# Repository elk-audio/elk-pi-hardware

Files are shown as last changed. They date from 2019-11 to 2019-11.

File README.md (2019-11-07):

# Elk Pi hardware documents

Full hardware project for the Elk Pi expansion Hat for the Raspberry Pi.

Directory contents:

  * [/Altium_files](Altium_files): Altium Project (ElkPi.PrjPcb), schematic documents (*.SchDoc), PCB document (ElkPi.PcbDoc), library files (Sika_revb.SchLib, Sika_revb.PcbLib)  
	  
  * [/Production_files/PCB_manufacturing](/Production_files/PCB_manufacturing): Gerber and drill files ready for PCB manufacturing  
	  
  * [/Production_files/PCB_Assembly](/Production_files/PCB_Assembly): Pick & Place file and assembly drawings (Top and Bottom)  
	  
  * [ElkPi_BOM.pdf](ElkPi_BOM.pdf): Bill Of Materials  
	  
  * [ElkPi_schematics.pdf](ElkPi_schematics.pdf): schematics capture file  
	  
---
Copyright 2019 *Modern Ancient Instruments Networked AB*, dba *Elk*

<br />This work is licensed under a <a rel="license" href="http://creativecommons.org/licenses/by-sa/4.0/">Creative Commons Attribution-ShareAlike 4.0 International License</a>.

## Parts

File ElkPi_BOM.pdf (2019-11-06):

| Elk Pi hat BOM | cc-by-sa Copyright Modern Ancient Instruments Networked AB, dba Elk 2019-11-06
# | Designator | Description | (per board) Qty | DNP | C | R | L | Footprint | rating | Dielectric | Manufacturer | Part Number | Manufacture r Lifecycle | Supplier | Supplier Part Number | Comment

## Passive Components

1 | C1_I1, C1_I2, C1_I3, C1_I4, C1_I5, C1_I6 | Cap Ceramic 10% | 6 | | 750pF | 0603 | 50V | C0G | Samsung | CL10C751JB8NNNC | Volume Production | Digi-Key | 1276-2336-6-ND (https://www.digikey.se/products/en?keywords=1276-2336-6-ND)
2 | C2_I1, C2_I2, C2_I3, C2_I4, C2_I5, C2_I6, C5_I1, C5_I2, C5_I3, C5_I4, C5_I5, C5_I6, C8, C9, C11, C13_O1, C13_O2, C13_O3, C25, C26, C27, C28, C29, C30, C32, C33, C35, C37, C42, C43, C45, C46, C47, C48, C49, C50, C51, C52, C53, C60, C63, C69, C73, C88, C89, C96, C97, C98, C99,C106 | Cap Ceramic 10% | 50 | | 100nF | 0603 | 16V | X7R | Samsung | CL10B104KO8NNNC | Volume Production | Digi-Key | 1276-1005-1-ND (https://www.digikey.se/products/en?keywords=1276-1005-1-ND)
3 | C62, C65 | Cap Ceramic 5% | 2 | | 220pF | 0603 | 50V | C0G | Samsung | CL10C221JB8NNNC | Volume Production | Digi-Key | 1276-1048-1-ND (https://www.digikey.se/products/en?keywords=1276-1048-1-ND)
4 C3_I1, C3_I2, C3_I3, C3_I4, C3_I5, C3_I6, C14_O1, C14_O2, C14_O3, C17_O1, C17_O2, | C17_O3, C19_O1, C19_O2, C19_O3, C22_O1, C22_O2, C22_O3, C102, C105 | Cap Aluminum Electrolytic 20% | 20 | | 22uF | Radial, Can - SMD | 35V | | Nichicon | UUQ1V220MCL1GB | Volume Production | Digi-Key | 493-17495-6-ND (https://www.digikey.se/products/en?keywords=493-17495-6-ND) | Height= 5.40mm Substitute: UWT1V220MCL1GB
5 | C4_I1, C4_I2, C4_I3, C4_I4, C4_I5, C4_I6 | Cap Ceramic 5% | 6 | | 22pF | 0603 | 50V | C0G | Samsung | CL10C220JB8NNNC | Volume Production | Digi-Key | 1276-1023-6-ND (https://www.digikey.se/products/en?keywords=1276-1023-6-ND)
6 | C6, C7, C58, C82 | Cap Ceramic 10% | 4 | | 1uF | 0805 | 16V | X7R | Samsung | CL21B105KAFNNNE | End of Life | Digi-Key | 1276-1066-6-ND (https://www.digikey.se/products/en?keywords=1276-1066-6-ND)
7 | C10 | Cap Ceramic 10% | 1 | | 1.5nF | 0603 | 16V | C0G | Samsung | CL10C152JB8NNNC | Volume Production | Digi-Key | 1276-2203-6-ND (https://www.digikey.se/products/en?keywords=1276-2203-6-ND)
8 C12_O1, C12_O2, C12_O3, C15_O1, C15_O2, C15_O3, C16_O1, C16_O2, C16_O3, C18_O1, | C18_O2, C18_O3, C20_O1, C20_O2, C20_O3, C21_O1, C21_O2, C21_O3 | Cap Ceramic 10% | 18 | | 1nF | 0603 | 16V | C0G | Samsung | CL10C102JB8NNNC | Volume Production | Digi-Key | 1276-1091-1-ND (https://www.digikey.se/products/en?keywords=1276-1091-1-ND)
9 | C23, C24 | Cap Ceramic 10% | 2 | | 16pF | 0603 | 50V | C0G | Samsung | CL10C160JB8NNNC | Volume Production | Digi-Key | 1276-2204-1-ND (https://www.digikey.se/products/en?keywords=1276-2204-1-ND)
10 | C31, C34, C36, C38, C39, C40, C41 | Capacitor Ceramic 20% | 7 | | 10uF | 0805 | 10V | X5R | Samsung | CL21A106MPFNNNE | Volume Production | Digi-Key | 1276-1144-6-ND (https://www.digikey.se/products/en?keywords=1276-1144-6-ND)
11 | C44, C67 | Cap Ceramic 10% | 2 | | 1uF | 0603 | 16V | X7R | Samsung | CL10B105KO8NFNC | Volume Production | Digi-Key | 1276-1943-6-ND (https://www.digikey.se/products/en?keywords=1276-1943-6-ND)
12 | C54, C56, C100, C103 | Cap Film 10% | 4 | | 1µF | 2824 | 50V | PEN | KEMET | LDECE4100KA5N00 | Volume Production | Digi-Key | 399-6416-1-ND (https://www.digikey.se/products/en?keywords=399-6416-1-ND)
13 | C55, C57 | Cap Aluminum Electrolytic 20% | 2 | | 100uF | Radial, Can - SMD | 25V | | Nichicon | UWT1E101MCL1GS | Volume Production | Digi-Key | 493-2190-1-ND (https://www.digikey.se/products/en?keywords=493-2190-1-ND) | Height = 7.70mm
14 | C59, C85 | Cap Ceramic 10% | 2 | | 10uF | 1210 | 25V | X7R | Samsung | CL32B106KAJNNNE | Volume Production | Digi-Key | 1276-1807-6-ND (https://www.digikey.se/products/en?keywords=1276-1807-6-ND)
15 | C61 | Capacitor Tantalum 10% | 1 | | 100uF | 2312 | 10V | | KEMET | T491C107K010AT | Volume Production | Digi-Key | 399-8338-1-ND (https://www.digikey.se/products/en?keywords=399-8338-1-ND)
16 | C64, C66 | Cap Ceramic 10% | 2 | | 330nF | 0603 | 16V | X7R | Samsung | CL10B334KO8NNNC | Volume Production | Digi-Key | 1276-2048-1-ND (https://www.digikey.se/products/en?keywords=1276-2048-1-ND)
17 | C68, C70, C71, C72, C74, C75, C76, C77, C78, C79, C80, C81 | Cap Ceramic 5% | 12 | | 47pF | 0603 | 50V | C0G | Samsung | CL10C470JB8NNNC | Volume Production | Digi-Key | 1276-1037-6-ND (https://www.digikey.se/products/en?keywords=1276-1037-6-ND)
18 | C83 | Cap Aluminium Electrolytic 20% | 1 | | 47µF | Radial, Can - SMD | 10V | | Panasonic | EEE1AA470WR | Volume Production | Digi-Key | PCE3875CT-ND (https://www.digikey.se/products/en?keywords=PCE3875CT-ND) | Height: 5.40mm
19 | C84, C86 | Cap Ceramic 10% | 2 | | 4.7uF | 0805 | 16V | X7R | Samsung | CL21B475KOFNFNE | Volume Production | Digi-Key | 1276-2970-6-ND (https://www.digikey.se/products/en?keywords=1276-2970-6-ND)
20 | C87 | Cap Ceramic 10% | 1 | | 22uF | 1210 | 25V | X7R | Samsung | CL32B226KAJNNNE | Volume Production | Digi-Key | 1276-3392-6-ND (https://www.digikey.se/products/en?keywords=1276-3392-6-ND)
21 | C90 | Cap Ceramic 10% | 1 | | 2.2uF | 0603 | 10V | X7R | Samsung | CL10B225KP8NNNC | Volume Production | Digi-Key | 1276-1134-6-ND (https://www.digikey.se/products/en?keywords=1276-1134-6-ND)
22 | C91 | Generic Capacitor slot | 1 | DNP | | 0603
23 | C92, C101, C104 | Cap Ceramic ±0.25pF | 3 | | 10pF | 0603 | 50V | C0G | Samsung | CL10C100CB8NNNC | Volume Production | Digi-Key | 1276-1069-1-ND (https://www.digikey.se/products/en?keywords=1276-1069-1-ND)
24 | C93 | Cap Multilayer Ceramic 20% | 1 | | 2.2uF | 0805 | 10V | X5R | Taiyo Yuden | LMK212BJ225MG-T | Volume Production | Digi-Key | 587-5919-1-ND (https://www.digikey.se/products/en?keywords=587-5919-1-ND)
25 | C94 | Cap Ceramic 20% | 1 | | 4.7uF | 1206 | 16V | X5R | KEMET | C1206C105M3RACT U | Volume Production | Digi-Key | 399-8148-6-ND (https://www.digikey.se/products/en?keywords=399-8148-6-ND)

| Elk Pi hat BOM | cc-by-sa Copyright Modern Ancient Instruments Networked AB, dba Elk 2019-11-06
# | Designator | Description | (per board) Qty | DNP | C | R | L | Footprint | rating | Dielectric | Manufacturer | Part Number | Manufacture r Lifecycle | Supplier | Supplier Part Number | Comment

26 | C95 | Cap Ceramic 20% | 1 | | 47uF | | | 1210 | 6.3V | X5R | Samsung | CL32A476MQJNNNE | Volume Production | Digi-Key | 1276-3381-6-ND (https://www.digikey.se/products/en?keywords=1276-3381-6-ND)
27 | D1 | Standard LED, Dome Lens, Red | 1 | | | | | 0603 | | | Kingbright | APTD1608LSURCK | Volume Production | Digi-Key | 754-2038-1-ND (https://www.digikey.se/products/en?keywords=754-2038-1-ND)
28 | D2, D5 | Standard LED, Dome Lens, Green | 2 | | | | | 0603 | | | Kingbright | APTD1608LCGCK | Volume Production | Digi-Key | 754-2037-1-ND (https://www.digikey.se/products/en?keywords=754-2037-1-ND)
29 | D3 | Diodes - General Purpose, Power, Switching 100volt 350mA 4ns | 1 | | | | | SOD-323F | | | ON Semiconductor | 1N914BWS | Volume Production | Digi-Key | 1N914BWSCT-ND (https://www.digikey.se/products/en?keywords=1N914BWSCT-ND)
30 | D4 | Diode Schottky 20V 500mA | 1 | | | | | SOD-123 | | | ON Semiconductor | MBR0520LT1G | Volume Production | Digi-Key | MBR0520LT1GOSCT- (https://www.digikey.se/products/en?keywords=MBR0520LT1GOSCT-ND) ND (https://www.digikey.se/products/en?keywords=MBR0520LT1GOSCT-ND)
31 | D6 | TVS DIODE 5VWM 9.2VC DO214AA | 1 | | | | | DO-214AA | | | Littelfuse Inc. | SMBJ5.0A | Volume Production | Digi-Key | SMBJ5.0ALFCT-ND (https://www.digikey.se/product-detail/en/littelfuse-inc/SMBJ5.0A/SMBJ5.0ALFCT-ND/285951)
32 | F1 | PTC Resettable Fuse 2.5A(hold) 5A(trip) | 1 | | | 100mR | | 1812 | 16V | | Bourns | MF-MSMF250/16X-2 | Volume Production | Digi-Key | MF-MSMF250/16X-2CT- ND (https://www.digikey.se/products/en?keywords=MF-MSMF250%2F16X-2CT-ND)
33 | FB1, FB2, FB3, FB4, FB6 | Signal Line Ferrite Bead, 0.5OHM1 kOhms @ 100MHz | 5 | | | | | 0603 | | | TDK | MMZ1608R102ATA00 | Volume Production | Digi-Key | 445-1548-1-ND (https://www.digikey.se/products/en?keywords=445-1548-1-ND)
34 | FB5 | Ferrite Bead, 470 Ohms @ 100MHz | 1 | | | | | 0603 | | | Murata | BLM18EG471SN1D | Volume Production | Digi-Key | 490-3993-1-ND (https://www.digikey.se/products/en?keywords=490-3993-1-ND)
35 | L1 | Shielded Wirewound Inductor 2.7A | 1 | | | | 2.2uH | Non Standard | | | Taiyo Yuden | NR6020T2R2N | Volume Production | Digi-Key | 587-2071-1-ND (https://www.digikey.se/products/en?keywords=587-2071-1-ND)
36 | L2 | INDUCTOR POWER 10UH 1.04A SMD | 1 | | | | 10uh | CR43-100MC | | | Sumida | CR43NP-100MC | Volume Production | Digi-Key | 308-2329-1-ND (https://www.digikey.se/products/en?keywords=308-2329-1-ND)
37 R1_I1, R1_I2, R1_I3, R1_I4, R1_I5, R1_I6, R5_I1, R5_I2, R5_I3, R5_I4, R5_I5, R5_I6, R6_I1, | R6_I2, R6_I3, R6_I4, R6_I5, R6_I6, R68, R69 | Resistor, Ceramic 1% | 20 | | | 1.5k | | 0603 | | | Bourns | CR0603-FX-1501ELF | Volume Production | Digi-Key | CR0603-FX-1501ELFCT- ND (https://www.digikey.se/products/en?keywords=CR0603-FX-1501ELFCT-ND)
38 | R2_I1, R2_I2, R2_I3, R2_I4, R2_I5, R2_I6 | Resistor, Ceramic 1% | 6 | | | 3k | | 0603 | | | Bourns | CR0603-FX-3001ELF | Volume Production | Digi-Key | CR0603-FX-3001ELFCT- (https://www.digikey.se/products/en?keywords=CR0603-FX-3001ELFCT-ND) ND (https://www.digikey.se/products/en?keywords=CR0603-FX-3001ELFCT-ND)
39 R3_I1, R3_I2, R3_I3, R3_I4, R3_I5, R3_I6, R7_I1, R7_I2, R7_I3, R7_I4, R7_I5, R7_I6, R13_O1, | R13_O2, R13_O3, R21_O1, R21_O2, R21_O3 | Resistor, Ceramic 1% | 18 | | | 47R | | 1206 | | | Bourns | CR1206-FX-47R0ELF | Volume Production | Digi-Key | CR1206-FX- 47R0ELFCT-ND (https://www.digikey.se/products/en?keywords=CR1206-FX-47R0ELFCT-ND)
40 | R4_I1, R4_I2, R4_I3, R4_I4, R4_I5, R4_I6, R38, R42, R59, R62, R64, R67, R80, R87, R94, R102, R125, R132 | Resistor, Ceramic 1% | 18 | | | 100k | | 0603 | | | Bourns | CR0603-FX-1003ELF | Volume Production | Digi-Key | CR0603-FX-1003ELFCT- (https://www.digikey.se/products/en?keywords=CR0603-FX-1003ELFCT-ND) ND (https://www.digikey.se/products/en?keywords=CR0603-FX-1003ELFCT-ND)
41 | R8, R53, R135 | Resistor, Ceramic 1% | 3 | | | 560R | | 0603 | | | Bourns | CR0603-FX-5600ELF | Volume Production | Digi-Key | CR0603-FX-5600ELFCT- (https://www.digikey.se/products/en?keywords=CR0603-FX-5600ELFCT-ND) ND (https://www.digikey.se/products/en?keywords=CR0603-FX-5600ELFCT-ND)
42 | R9 | Resistor, Ceramic 1% | 1 | | | 604k | | 0603 | | | Bourns | CR0603-FX-6043ELF | Volume Production | Mouser | 652-CR0603-FX6043ELF (https://eu.mouser.com/ProductDetail/Bourns/CR0603-FX-6043ELF)
43 R10_O1, R10_O2, R10_O3, R17_O1, R17_O2, R17_O3, R18_O1, R18_O2, R18_O3, R25_O1, | R25_O2, R25_O3 | Resistor, Ceramic 1% | 12 | 3.6k | 0603 | Bourns | CR0603-FX-3601ELF | Volume Production | Digi-Key | CR0603-FX-3601ELFCT- ND (https://www.digikey.se/products/en?keywords=CR0603-FX-3601ELFCT-ND)
44 R11_O1, R11_O2, R11_O3, R14_O1, R14_O2, R14_O3, R19_O1, R19_O2, R19_O3, R22_O1, | R22_O2, R22_O3 | Resistor, Ceramic 1% | 12 | 6.8k | 0603 | Bourns | CR0603-FX-6801ELF | Volume Production | Digi-Key | CR0603-FX-6801ELFCT- ND (https://www.digikey.se/products/en?keywords=CR0603-FX-6801ELFCT-ND)
45 R12_O1, R12_O2, R12_O3, R15_O1, R15_O2, R15_O3, R20_O1, R20_O2, R20_O3, R23_O1, | R23_O2, R23_O3 | Resistor, Ceramic 1% | 12 | 360R | 0603 | Bourns | CR0603-FX-3600ELF | End of Life | Digi-Key | CR0603-FX-3600ELFCT- ND (https://www.digikey.se/products/en?keywords=CR0603-FX-3600ELFCT-ND)
46 | R16_O1, R16_O2, R16_O3, R24_O1, R24_O2, R24_O3, R58, R61, R63, R66, R127, R134 | Resistor, Ceramic 1% | 12 | 47k | 0603 | Bourns | CR0603-FX-4702ELF | Volume Production | Digi-Key | CR0603-FX-4702ELFCT- (https://www.digikey.se/products/en?keywords=CR0603-FX-4702ELFCT-ND) ND (https://www.digikey.se/products/en?keywords=CR0603-FX-4702ELFCT-ND)
47 | R26, R32,R33, R34, R106, R126, R133 | Resistor, Ceramic 1% | 7 | 0R | 0603 | Bourns | CR0603-J/-000ELF | Volume Production | Digi-Key | CR0603-J/-000ELFCT- (https://www.digikey.se/products/en?keywords=CR0603-J%2F-000ELFCT-ND) ND (https://www.digikey.se/products/en?keywords=CR0603-J%2F-000ELFCT-ND)
48 | R27, R28, R29, R43, R44, R45, R46, R47, R48, R49, R55, R56, R76, R114, R115, R116, R117, R118, R119, R120 | Resistor, Ceramic 1% | 20 | 22R | 0603 | Samsung | RC1608F220CS | Volume Production | Digi-Key | 1276-4511-6-ND (https://www.digikey.se/products/en?keywords=1276-4511-6-ND)
49 | R35, R37, R39, R41, R112 | Resistor, Ceramic 1% | 5 | 1k | 0603 | Bourns | CR0603-FX-1001ELF | Volume Production | Digi-Key | CR0603-FX-1001ELFCT- (https://www.digikey.se/products/en?keywords=CR0603-FX-1001ELFCT-ND) ND (https://www.digikey.se/products/en?keywords=CR0603-FX-1001ELFCT-ND)
50 | R50 | Potentiometers Dual Unit 10mm, 15A insertion (2mm) | 1 | 10k | Non Standard | Alps Electric | RK10J12E0A0A | Volume Production | Mouser | 688-RK10J12E0A0A (https://eu.mouser.com/ProductDetail/ALPS/RK10J12E0A0A)
51 | R52, R54 | Resistor, Ceramic 1% | 2 | 20k | 0603 | Bourns | CR0603-FX-2002ELF | Volume Production | Digi-Key | CR0603-FX-2002ELFCT- (https://www.digikey.se/products/en?keywords=CR0603-FX-2002ELFCT-ND) ND (https://www.digikey.se/products/en?keywords=CR0603-FX-2002ELFCT-ND)
52 | R60, R65, R82, R88, R96, R103, R122, R129 | Resistor, Ceramic 1% | 8 | 47R | 0603 | Bourns | CR0603-FX-47R0ELF | Volume Production | Digi-Key | CR0603-FX- (https://www.digikey.se/products/en?keywords=CR0603-FX-47R0ELFCT-ND) 47R0ELFCT-ND (https://www.digikey.se/products/en?keywords=CR0603-FX-47R0ELFCT-ND)

| Elk Pi hat BOM | cc-by-sa Copyright Modern Ancient Instruments Networked AB, dba Elk 2019-11-06
# | Designator | Description | (per board) Qty | DNP | C | R | L | Footprint | rating | Dielectric | Manufacturer | Part Number | Manufacture r Lifecycle | Supplier | Supplier Part Number | Comment

53 | R70 | Resistor, Ceramic 1% | 1 | | | 470 | | 0603 | | | Bourns | CR0603-FX-4700ELF | Volume Production | Digi-Key | CR0603-FX-4700ELFCT- (https://www.digikey.se/products/en?keywords=CR0603-FX-4700ELFCT-ND) ND (https://www.digikey.se/products/en?keywords=CR0603-FX-4700ELFCT-ND)
54 | R71 | Resistor, Ceramic 1% | 1 | | | 220R | | 0603 | | | Bourns | CR0603-FX-2200ELF | Volume Production | Digi-Key | CR0603-FX-2200ELFCT- (https://www.digikey.se/products/en?keywords=CR0603-FX-2200ELFCT-ND) ND (https://www.digikey.se/products/en?keywords=CR0603-FX-2200ELFCT-ND)
55 | R72, R75 | Resistor, Ceramic 1% | 2 | | | 51R | | 0603 | | | Bourns | CR0603-FX-51R0ELF | Volume Production | Digi-Key | CR0603-FX- (https://www.digikey.se/products/en?keywords=CR0603-FX-51R0ELFCT-ND) 51R0ELFCT-ND (https://www.digikey.se/products/en?keywords=CR0603-FX-51R0ELFCT-ND)
56 | R31, R73, R74, R110 | Resistor, Ceramic 1% | 4 | DNP | | 0R | | 0603 | | | Bourns | CR0603-J/-000ELF | Volume Production | Digi-Key | CR0603-J/-000ELFCT- (https://www.digikey.se/products/en?keywords=CR0603-J%2F-000ELFCT-ND) ND (https://www.digikey.se/products/en?keywords=CR0603-J%2F-000ELFCT-ND)
57 | R77, R30, R36, R40, R51, R57, R113, R136, R137 | Resistor, Ceramic 1% | 9 | | | 10k | | 0603 | | | Bourns | CR0603-FX-1002ELF | Volume Production | Digi-Key | CR0603-FX-1002ELFCT- (https://www.digikey.se/products/en?keywords=CR0603-FX-1002ELFCT-ND) ND (https://www.digikey.se/products/en?keywords=CR0603-FX-1002ELFCT-ND)
58 | R78, R85, R92, R99 | Resistor, Ceramic 1% | 4 | | | 150k | | 0603 | | | Bourns | CR0603-FX-1503ELF | Volume Production | Digi-Key | CR0603-FX-1503ELFCT- (https://www.digikey.se/products/en?keywords=CR0603-FX-1503ELFCT-ND) ND (https://www.digikey.se/products/en?keywords=CR0603-FX-1503ELFCT-ND)
59 | R79, R81, R83, R84, R86, R89, R90, R91, R93, R95, R97, R98, R100, R101, R104, R105 | Resistor, Ceramic 1% | 16 | | | 49.9k | | 0603 | | | Bourns | CR0603-FX-4992ELF | Volume Production | Digi-Key | CR0603-FX-4992ELFCT- (https://www.digikey.se/products/en?keywords=CR0603-FX-4992ELFCT-ND) ND (https://www.digikey.se/products/en?keywords=CR0603-FX-4992ELFCT-ND)
60 | R107 | Resistor, Ceramic 1% | 1 | | | 15k | | 0603 | | | Bourns | CR0603-FX-1502ELF | Volume Production | Digi-Key | CR0603-FX-1502ELFCT- (https://www.digikey.se/products/en?keywords=CR0603-FX-1502ELFCT-ND) ND (https://www.digikey.se/products/en?keywords=CR0603-FX-1502ELFCT-ND)
61 | R108 | Resistor, Ceramic 0.1% | 1 | | | 2.32k | | 0603 | | | Panasonic | ERA-3AEB2321V | Volume Production | Digi-Key | P2.32KDBCT-ND (https://www.digikey.se/products/en?keywords=P2.32KDBCT-ND)
62 | R109 | Resistor, Ceramic 1% | 1 | | | 4.7k | | 0603 | | | Bourns | CR0603-FX-4701ELF | Volume Production | Digi-Key | CR0603-FX-4701ELFCT- (https://www.digikey.se/products/en?keywords=CR0603-FX-4701ELFCT-ND) ND (https://www.digikey.se/products/en?keywords=CR0603-FX-4701ELFCT-ND)
63 | R111 | Resistor, Ceramic 1% | 1 | | | 102k | | 0603 | | | Bourns | CR0603-FX-1023ELF | End of Life | Digi-Key | CR0603-FX-1023ELFCT- (https://www.digikey.se/products/en?keywords=CR0603-FX-1023ELFCT-ND) ND (https://www.digikey.se/products/en?keywords=CR0603-FX-1023ELFCT-ND)
64 | R123, R124,R130, R131 | Resistor, Ceramic 1% | 4 | | | 2M | | 0603 | | | Panasonic | ERJ-3EKF2004V | Volume Production | Digi-Key | P2.00MHCT-ND (https://www.digikey.se/product-detail/en/panasonic-electronic-components/ERJ-3EKF2004V/P2.00MHCT-ND/282732)
65 | X1 | Crystal 27.0000MHZ 10pF | 1 | | | | | 4-SMD, No Lead | | | TXC | 7M-27.000MEEQ-T | Volume Production | Digi-Key | 887-1328-2-ND (https://www.digikey.se/products/en?keywords=887-1328-2-ND) | Size: 3.2mm x 2.5mm

## Active Components

66 | T1, T2 | Transistor NPN 40V 0.2A | 2 | SOT-23-3 | ON Semiconductor | MMBT3904LT1G | Volume Production | Digi-Key | MMBT3904LT1GOSCT- (https://www.digikey.se/product-detail/en/on-semiconductor/MMBT3904LT1G/MMBT3904LT1GOSCT-ND/1139813) ND (https://www.digikey.se/product-detail/en/on-semiconductor/MMBT3904LT1G/MMBT3904LT1GOSCT-ND/1139813)
67 | U1_I1, U1_I2, U1_I3, U1_I4, U1_I5, U1_I6, U6_O1, U6_O2, U6_O3, U28 | Opamp Audio 2 circuit | 10 | 8-SOIC | Texas Instruments | OPA2134UA/2K5 | Volume Production | Digi-Key | 296-22024-1-ND (https://www.digikey.se/products/en?keywords=296-22024-1-ND)
68 | U2 | ADC 10BIT SAR | 1 | 8VSSOP | Texas Instruments | ADS7041IDCUT | Volume Production | Digi-Key | 296-39577-1-ND (https://www.digikey.se/products/en?keywords=296-39577-1-ND)
69 | U3, U8 | Opamp General Purpose 1 Circuit Rail-to-Rail | 2 | SOT-23-5 | Texas Instruments | OPA314AIDBVT | Volume Production | Digi-Key | 296-39122-1-ND (https://www.digikey.se/products/en?keywords=296-39122-1-ND)
70 | U4 | MUX/DEMUX 1X16 | 1 | 24-TSSOP | NXP Semiconductors | 74HC4067PW,112 | Volume Production | Digi-Key | 1727-3311-ND (https://www.digikey.se/products/en?keywords=1727-3311-ND)
71 | U5, U13, U15, U16, U18 | Shift Shift Register 1 Element 8 Bit | 5 | 16-TSSOP | Nexperia | 74HC595PW-Q100, 118 | Unknown | Digi-Key | 1727-1012-1-ND (https://www.digikey.se/products/en?keywords=1727-1012-1-ND)
72 | U7 | CLK Generator 200MHZ | 1 | 10MSOP | Silicon Labs | SI5351A-B-GT | Volume Production | Digi-Key | 336-2399-5-ND (https://www.digikey.se/products/en?keywords=336-2399-5-ND)
73 | U9 | CPLD CoolRunner II 64MC 6.7NS | 1 | 44VQFP | Xilinx | XC2C64A-7VQG44C | Volume Production | Digi-Key | 122-1410-ND (https://www.digikey.se/products/en?keywords=122-1410-ND)
74 | U10 | Linear Voltage Regulator IC 1 Output 150mA | 1 | SOT-23-5 | TI National Semiconductor | LP3990MF-1.8/NOPB | Volume Production | Digi-Key | LP3990MF-1.8/NOPBCT- ND (https://www.digikey.se/products/en?keywords=LP3990MF-1.8%2FNOPBCT-ND)
75 | U11 | Buffer, Non-Inverting 4 Element 1 Bit per Element 3-State Output | 1 | 14-SOIC | Texas Instruments | SN74HCT125DR | Volume Production | Digi-Key | 296-1206-1-ND (https://www.digikey.se/products/en?keywords=296-1206-1-ND)
76 | U12, U14, U17, U19 | Shift Register Single 8-Bit Serial/Parallel to Serial 16-Pin | 4 | 16-TSSOP | Nexperia | 74HC165PW,112 | Unknown | Digi-Key | 1727-3245-ND (https://www.digikey.se/products/en?keywords=1727-3245-ND)
77 | U20 | Amplifier IC Headphones, 2-Channel (Stereo) Class AB | 1 | 8-SOIC | Texas Instruments | TPA6111A2DR | Volume Production | Digi-Key | 296-10846-1-ND (https://www.digikey.se/products/en?keywords=296-10846-1-ND)
78 | U21 | Opamp General Purpose 2 Circuit Rail-to-Rail | 1 | 8-VSSOP | Texas Instruments | OPA2171AIDCUT | Volume Production | Digi-Key | 296-29514-1-ND (https://www.digikey.se/products/en?keywords=296-29514-1-ND)

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

79 | U22 | Optoisolator Darlington with Base Output 5000Vrms 1 Channel | 1 | | | | | 8-SMD | | | Isocom | 6N139SMT/R | Volume Production | Digi-Key | 6N139SMCT-ND (https://www.digikey.se/products/en?keywords=6N139SMCT-ND)
80 | U23, U24 | Opamp General Purpose 4 Circuit Rail-to-Rail | 2 | | | | | 14-TSSOP | | | Texas Instruments | OPA4171AIPWR | Volume Production | Digi-Key | 296-29651-1-ND (https://www.digikey.se/products/en?keywords=296-29651-1-ND)
81 | U25 | Buck Switching Regulator IC Positive Adjustable 0.8V 1 Output 1.5A | 1 | | | | | 6-VDFN Exposed Pad | | | STMicroelectroni cs | ST1S06APUR | Volume Production | Digi-Key | 497-6309-1-ND (https://www.digikey.se/products/en?keywords=497-6309-1-ND)
82 U26 | | Boost, Flyback, SEPIC Switching Regulator IC Positive Adjustable 2.45V 1 Output 1A (Switch) | 1 TSOT-23-5 | | | | | | | | Analog Devices / Linear Technology | LT1930AES5#TRMP BF | Volume Production | Digi-Key | LT1930AES5#TRMPBFC
83 | U27 | Linear Voltage Regulator IC 1 Output 250mA | 1 | | | | | 8-SO | | | STMicroelectroni cs | L4931CD120-TR | Volume Production | Digi-Key | 497-7761-1-ND (https://www.digikey.se/products/en?keywords=497-7761-1-ND)
84 | U29 | Inverter IC 2 Channel Schmitt Trigger | 1 | | | | | SC-88/SC70- 6/SOT-363 | | | ON Semiconductor | NL27WZ14DFT2G | Volume Production | Digi-Key | NL27WZ14DFT2GOSCT
85 | IC1 | 6-In/8-Out Audio Codec With Differential Input/Output | 1 | | | | | 64HTQFP | | | Texas Instruments | PCM3168APAPR | Volume Production | Digi-Key | 296-31710-1-ND (https://www.digikey.se/products/en?keywords=296-31710-1-ND)

T-ND (https://www.digikey.se/products/en?keywords=LT1930AES5%23TRMPBFCT-ND)

-ND (https://www.digikey.se/products/en?keywords=NL27WZ14DFT2GOSCT-ND)

## Headers and connectors

86 | J1 | CONN HEADER VERT 6POS 2.54 MM | 1 | DNP | 1X6 | Amphenol FCI | 68000-406HLF | Volume Production | Digi-Key | 609-3263-ND (https://www.digikey.se/product-detail/en/amphenol-icc-fci/68000-406HLF/609-3263-ND/1878471)
87 | J2, J6 | CONN RCPT 26POS 2.54MM | 2 | | 2X13 | Harwin | M20-7831346 | Volume Production | Digi-Key | 952-2548-ND (https://www.digikey.se/product-detail/en/harwin-inc/M20-7831346/952-2548-ND/3919503)
88 | J3, J4 | CONN RCPT 40POS 2.54MM | 2 | | 2X20 | Harwin | M20-7832046 | Volume Production | Digi-Key | 952-2150-ND (https://www.digikey.se/products/en?keywords=952-2150-ND)
89 | J5 | STEREO JACK, IP67, 3.5, 5 CONDUC | 1 | | Non Standard | CUI | SJ-3541AS-SMT-TR- 67 | Volume Production | Mouser | 490-SJ- (https://eu.mouser.com/ProductDetail/CUI/SJ-3541AS-SMT-TR-67) 3541ASSMTTR67
90 | J13 | CONN JACK STEREO 3.5MM R/A | 1 | | Non Standsrd | Switchcraft | 35RAPC4BH3 | | Mouser | 490-SJ- (https://eu.mouser.com/ProductDetail/Switchcraft/35RAPC4BH3) 3541ASSMTTR67 (https://eu.mouser.com/ProductDetail/Switchcraft/35RAPC4BH3)
91 | J7, J8, J10, J11, J14 | CONN HEADER VERT 6POS 2.54 MM | 5 | | 2X3 | Harwin | M20-9980346 | Volume Production | Digi-Key | 952-2121-ND (https://www.digikey.se/products/en?keywords=952-2121-ND)
92 | J9 | RASPBERRY PI GPIO TALL HEADER | 1 | | | Adafruit | PRT-14017 | Volume Production | Digi-Key | 1568-1462-ND (https://www.digikey.se/products/en?keywords=1568-1462-ND) | Alternative: here
93 | J12 | CONN HEADER VERT 2POS 2.54 MM | 1 | DNP | 2X1
94 | TP1, TP2, TP3, TP4, TP5, TP6, TP7, TP8, TP9, TP10 | PLATE, DIAL, 2.188IN DIA; Label Type: Dia; Label Size: 2.3/16"; | 10 | DNP | PCB- 160ru2rcn7fnmbmh | Keystone Electronics | 5000 | Volume Production | Digi-Key | 36-5000-ND

434

## Hardware Accessories

18 mm m-f spacer | 4 | DNB | RAF Electronic Hardware | M2113-2545-AL | Mouser | 761-M2113-2545-AL (https://eu.mouser.com/ProductDetail/RAF-Electronic-Hardware/M2113-2545-AL) | 19 mm here (https://eu.mouser.com/ProductDetail/RAF-Electronic-Hardware/M2114-2545-AL)
Standoffs & Spacers 5mm METRIC STANDOFF | 4 | DNB | RAF Electronic Hardware | M1252-2545-AL | Mouser | 761-M1252-2545-AL (https://eu.mouser.com/ProductDetail/RAF-Electronic-Hardware/M1252-2545-AL)
Headers & Wire Housings .100" Multi Position Shunt | 5 | DNB | | MNT-102-BK-T | Mouser | 200-MNT102BKT

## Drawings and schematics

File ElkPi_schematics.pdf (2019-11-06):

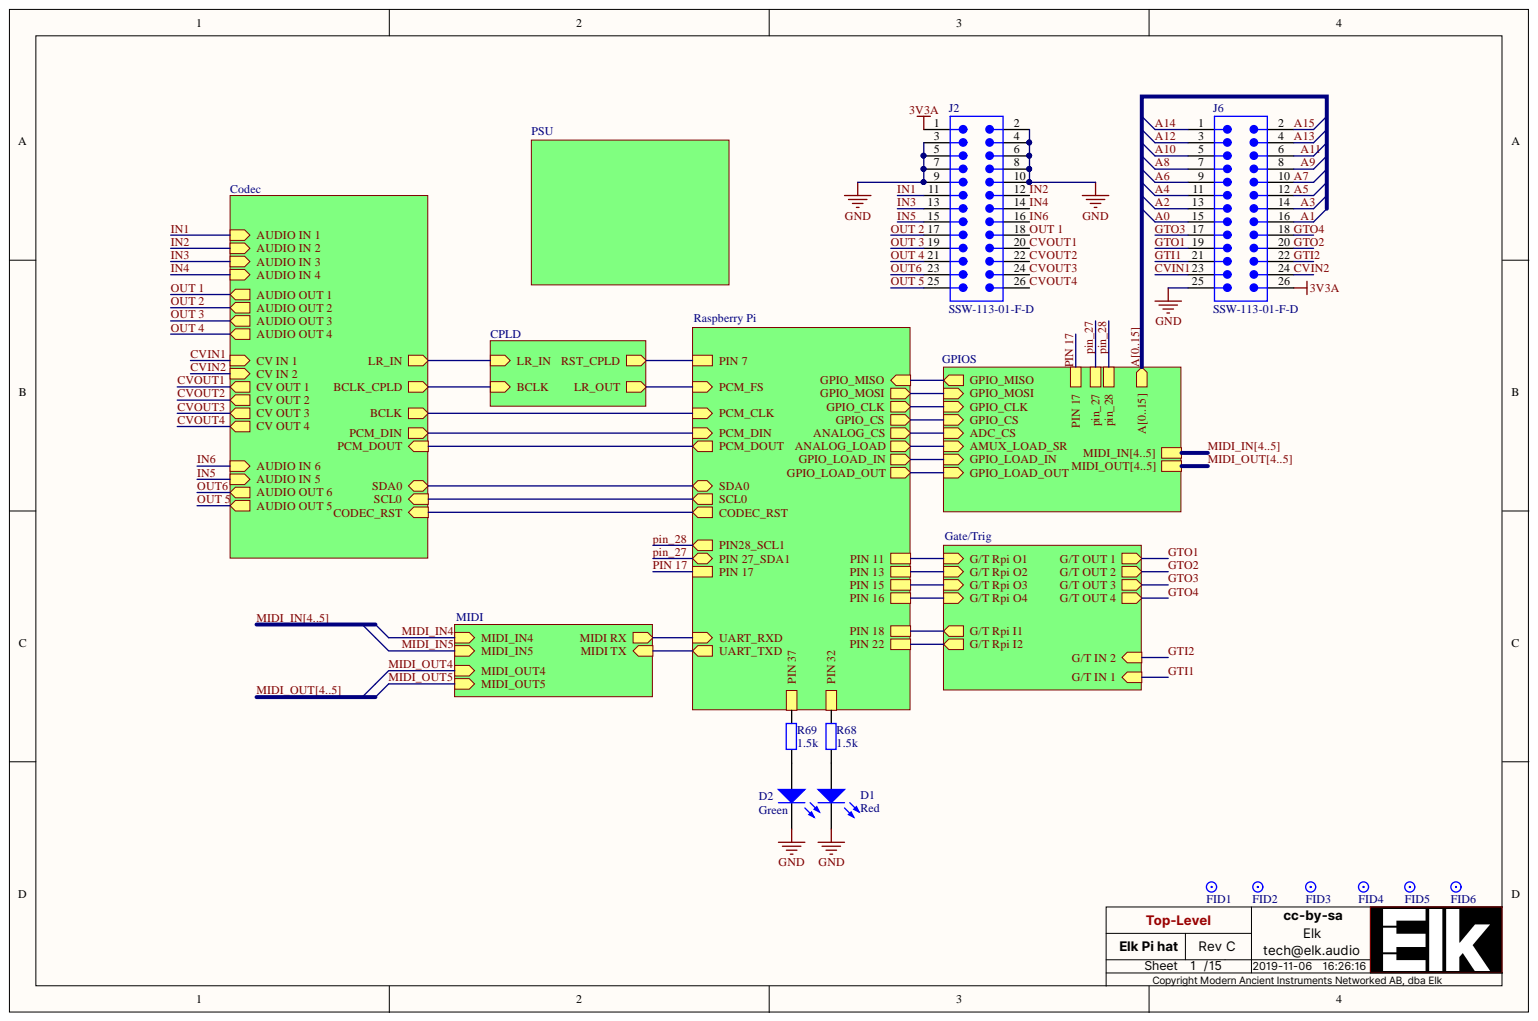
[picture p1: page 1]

Top-Level | cc-by-sa Elk tech@elk.audio

Elk Pi hat | Rev C
Sheet 1 / 15 | 2019-11-06 16:26:16

Copyright Modern Ancient Instruments Networked AB, dba Elk

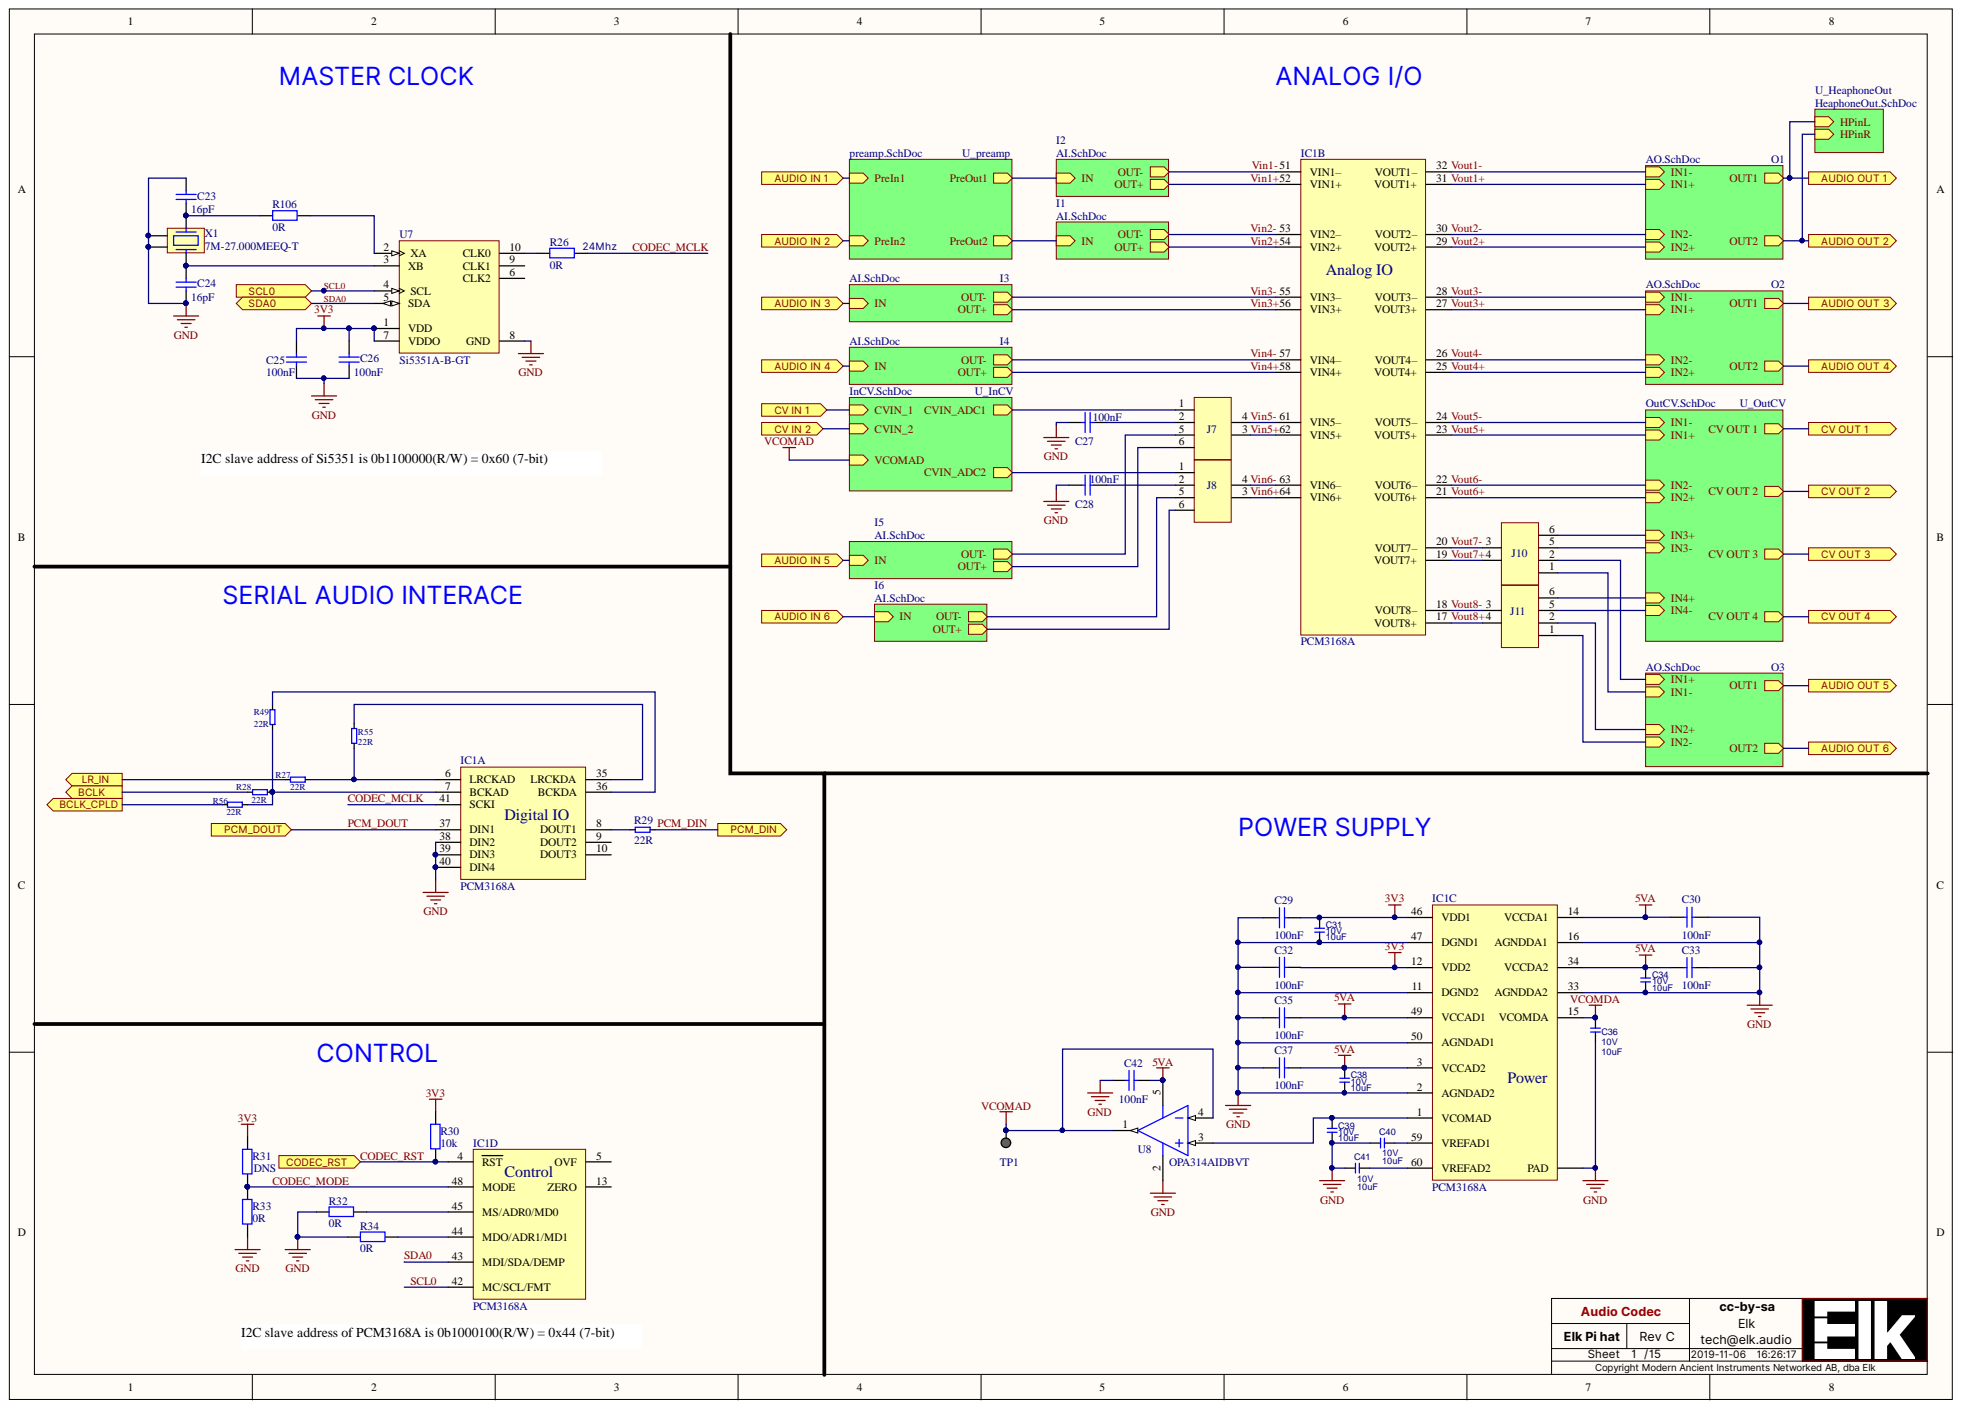
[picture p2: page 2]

Vin1+ | VIN1+ 52 | Vout1+ | IN1-OUT1 IN1+ IN2-OUT2 IN2+

VIN2– 53 | Vout2-

Vin4+ | VIN4+ 58 | Vout4+

VIN5– 61

I2C slave address of Si5351 is 0b1100000(R/W) = 0x60 (7-bit)

C28 | 6
GND

5 | | 3 Vin6+ | VIN6+ 64 | Vout6+

IN OUT-OUT+ | | | | | Vout7+ 4 | 2

Vout8-3 | | 1

4 | J11 Vout8+ | 2

VCOMAD 1

C39 C40 | VREFAD1 59

I2C slave address of PCM3168A is 0b1000100(R/W) = 0x44 (7-bit)

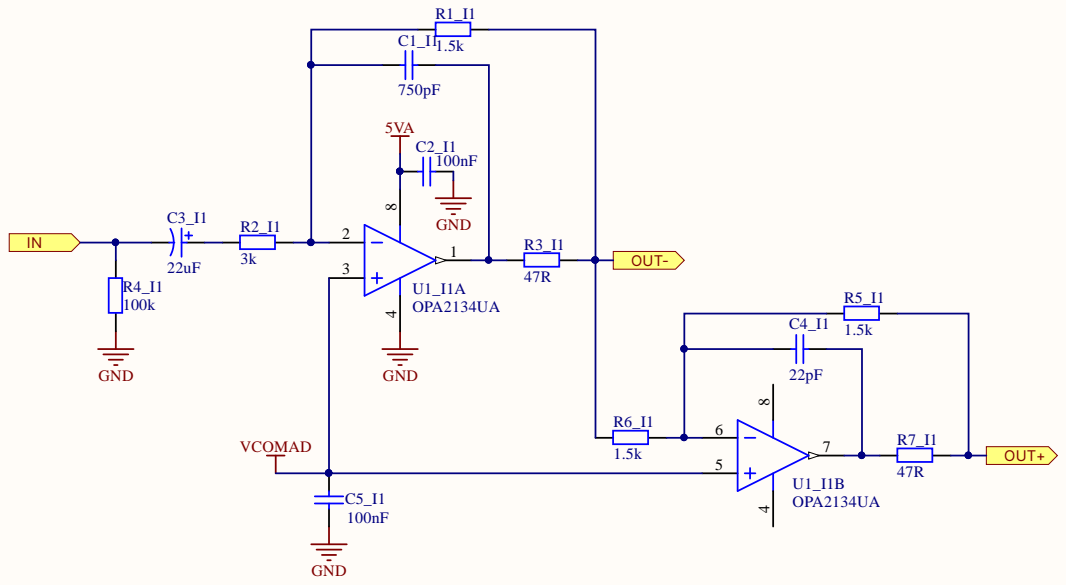
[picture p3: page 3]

Audio Input Filter | cc-by-sa Elk tech@elk.audio

Elk Pi hat | Rev C
Sheet 3 / 15

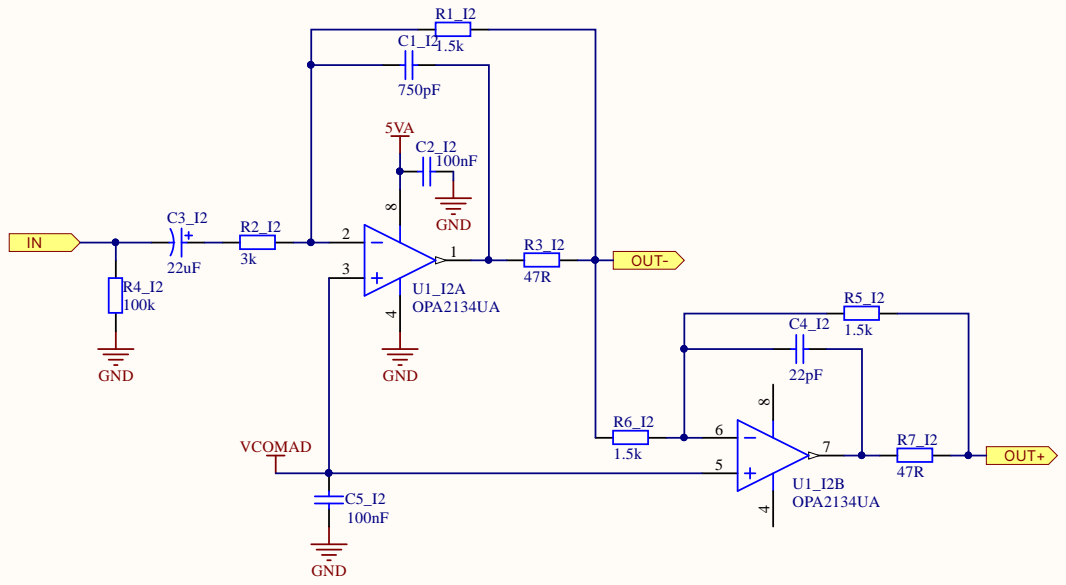
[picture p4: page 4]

Audio Input Filter | cc-by-sa Elk tech@elk.audio

Elk Pi hat | Rev C
Sheet 3 / 15

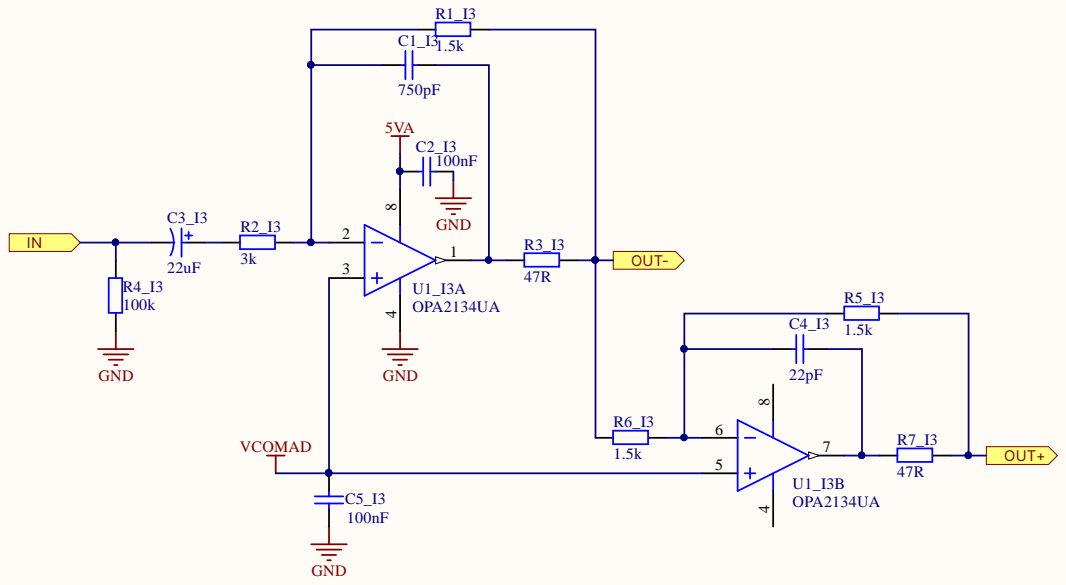
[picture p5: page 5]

Audio Input Filter | cc-by-sa Elk tech@elk.audio

Elk Pi hat | Rev C
Sheet 3 / 15

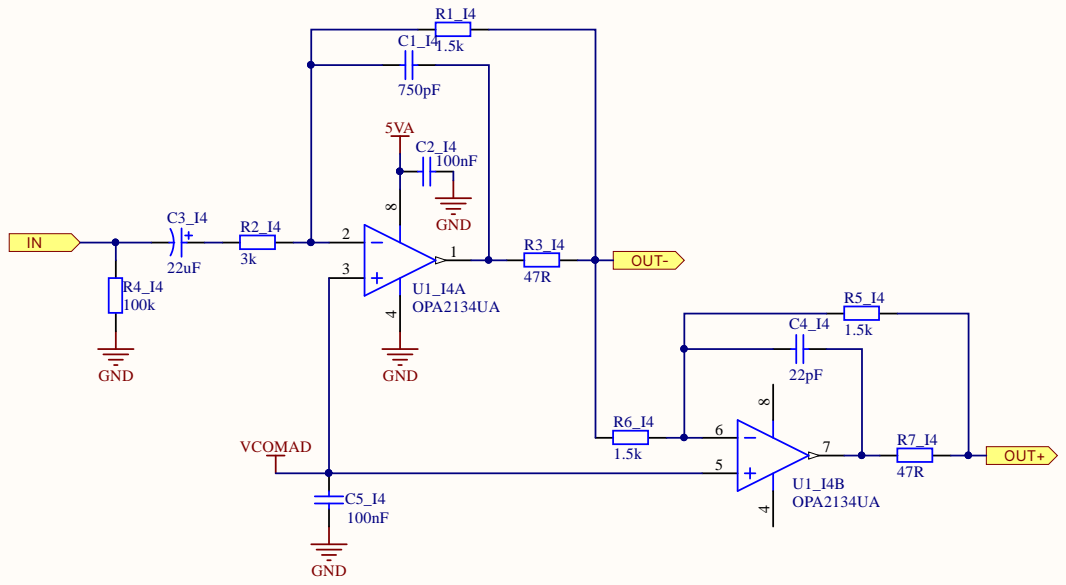
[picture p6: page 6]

Audio Input Filter | cc-by-sa Elk tech@elk.audio

Elk Pi hat | Rev C
Sheet 3 / 15

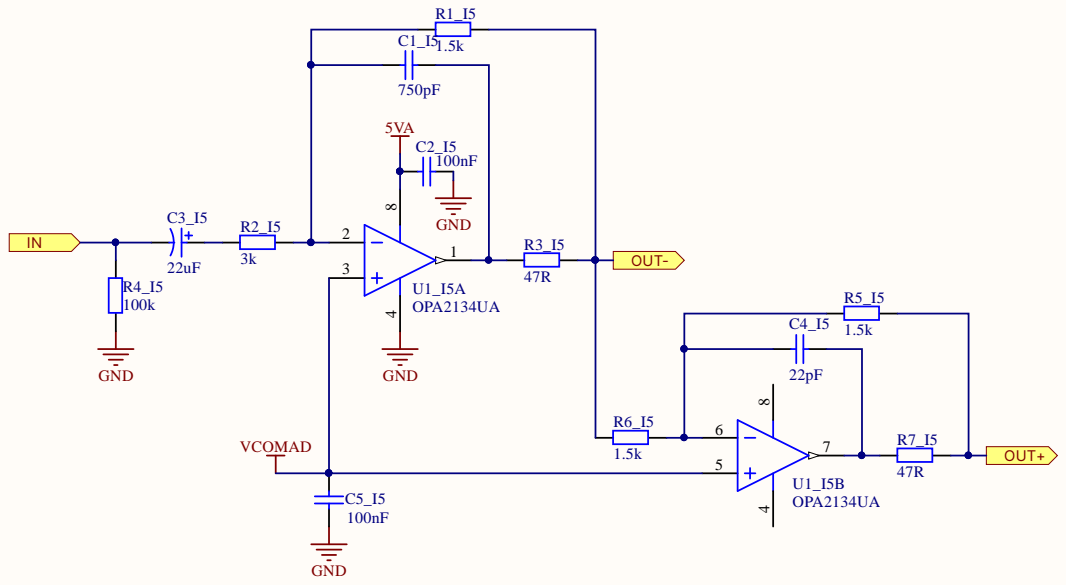
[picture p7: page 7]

Audio Input Filter | cc-by-sa Elk tech@elk.audio

Elk Pi hat | Rev C
Sheet 3 / 15

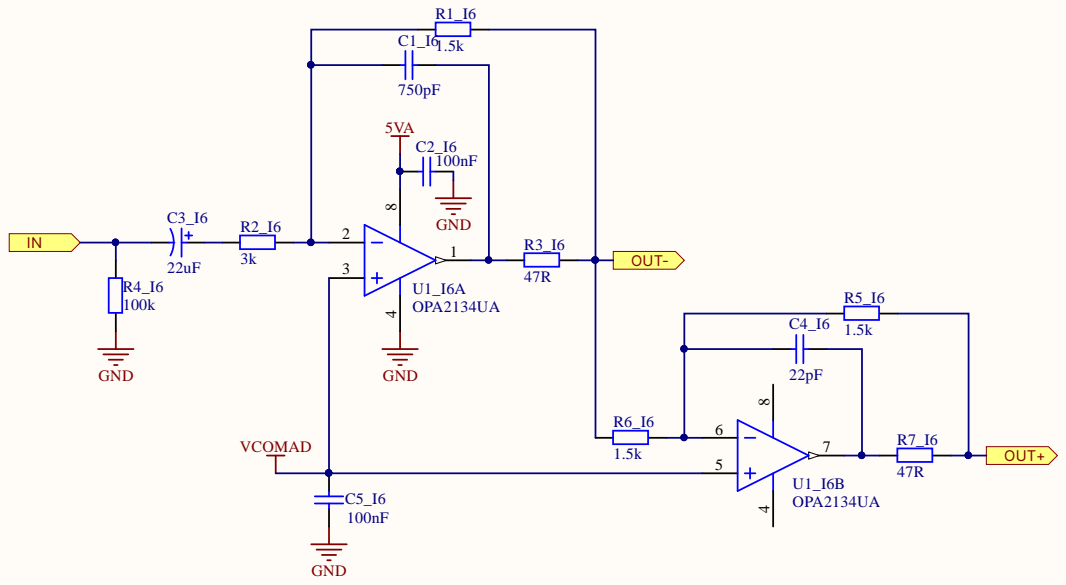
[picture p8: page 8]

Audio Input Filter | cc-by-sa Elk tech@elk.audio

Elk Pi hat | Rev C
Sheet 3 / 15

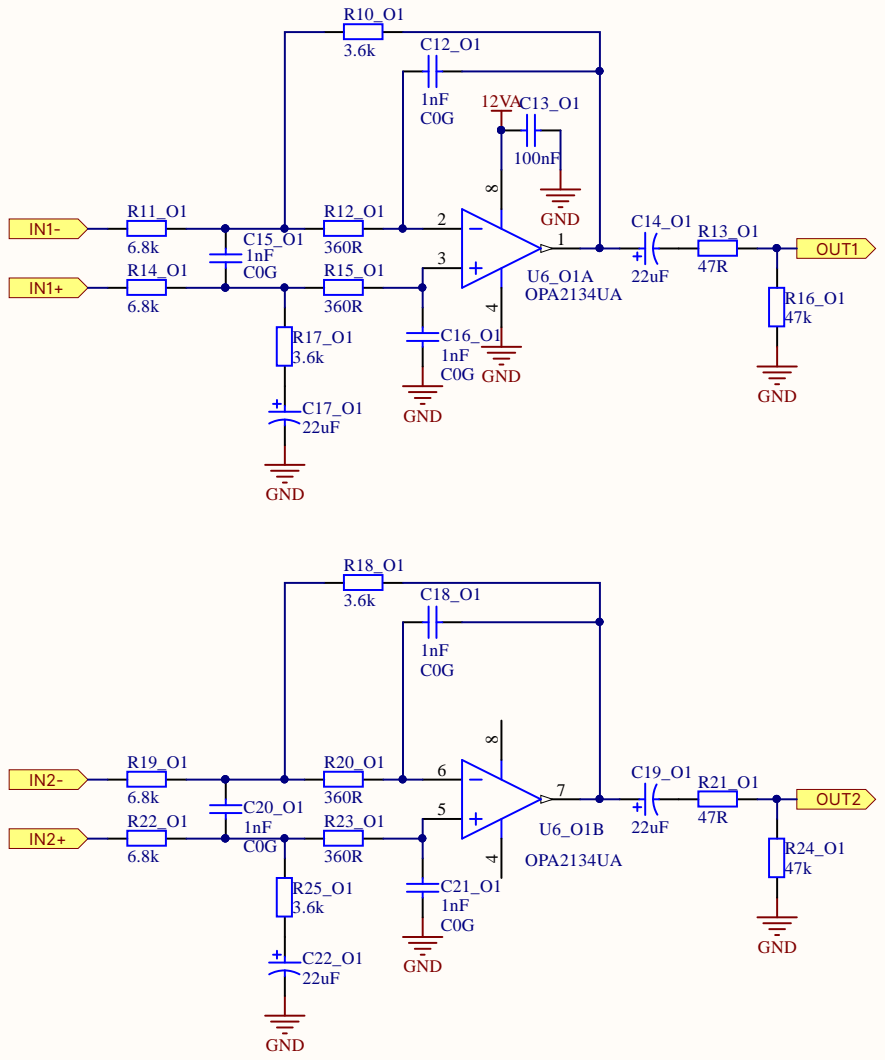
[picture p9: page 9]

Audio Output Filter | cc-by-sa Elk tech@elk.audio

Elk Pi hat | Rev C
Sheet 4 / 15

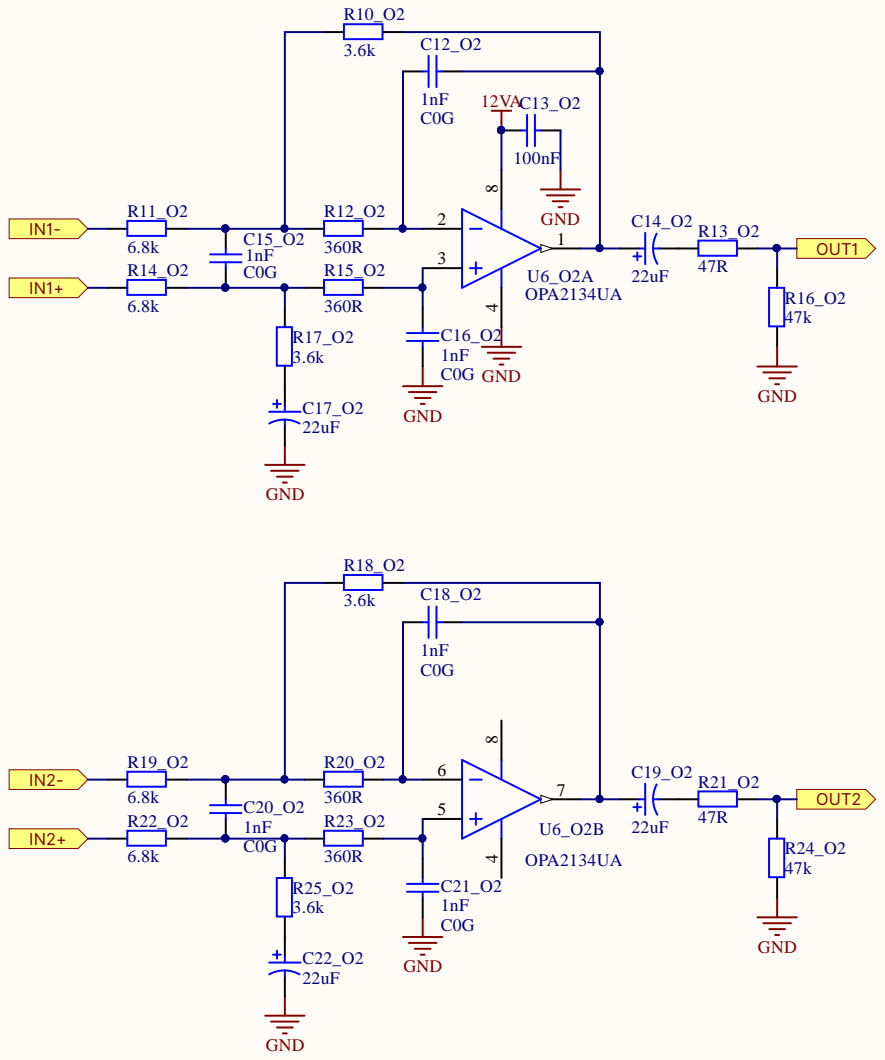
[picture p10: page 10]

Audio Output Filter | cc-by-sa Elk tech@elk.audio

Elk Pi hat | Rev C
Sheet 4 / 15

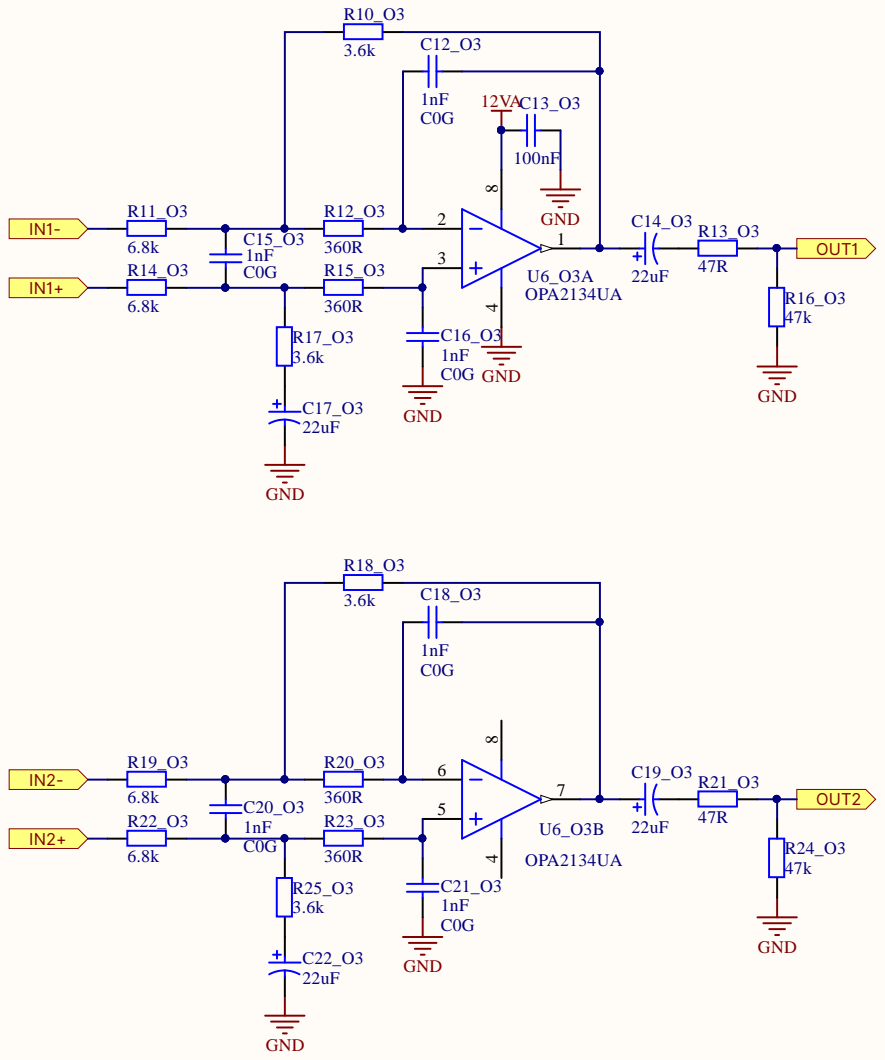
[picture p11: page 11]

Audio Output Filter | cc-by-sa Elk tech@elk.audio

Elk Pi hat | Rev C
Sheet 4 / 15

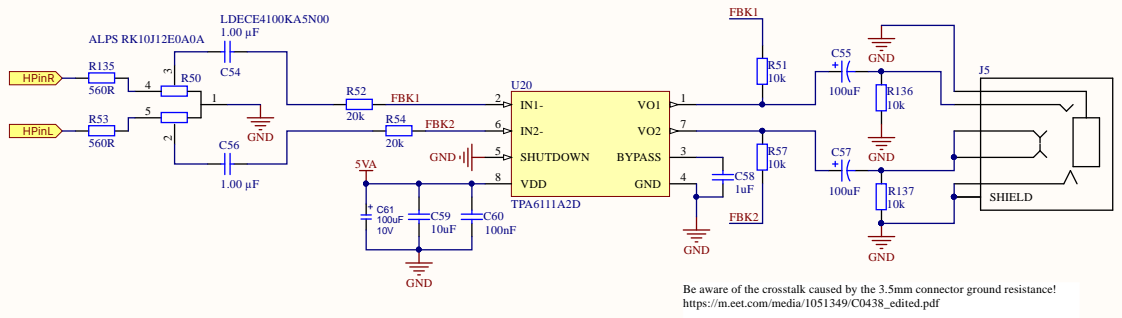
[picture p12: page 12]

Headpho ne O u tpu t | c c-by-sa Elk tech@elk.au dio

Elk Pi ha t | Re v C
Sh e e t 5 / 1 5 | -11-6 16:26:20


CV Input | cc-by-sa Elk tech@elk.audio

Elk Pi hat | Rev C
Sheet 6 / 15


C V O u tpu t | c c-by-sa Elk tech@elk.au dio

Elk Pi ha t | Re v C
Sh e e t 7 / 1 5 | -11-6 16:26:21


S tereo P rea m p | c c-by-sa Elk tech@elk.au dio

Elk Pi ha t | Re v C
Sh e e t 8 / 1 5 | -11-6 16:26:21


Gate/Trig | cc-by-sa Elk tech@elk.audio

Elk Pi hat | Rev C
Sheet 9 / 15


G PIOs | cc-by-s a Elk tech@elk.audio

Elk Pi h a t | Rev C
She e t / | -11-6 16:26:22


1 8
1 7
1 6

A n alog I npu t s | c c-by-sa Elk tech@elk.au dio

Elk Pi ha t | Re v C
Sh e e t 1 1 / 1 5 | -11-6 16:26:23


MIDI | cc-by-sa Elk tech@elk.audio

Elk Pi hat | Rev C
Sheet 12 / 15


Power Supply Unit | cc-by-sa Elk tech@elk.audio

Elk Pi hat | Rev C
Sheet 13 / 15


WARNING: IT IS NOT
POSSIBLE TO USE THE
UART AND THE MIDI
PINS AT THE SAME TIME,
SINCE THEY SHARE THE
SAME INTERFACE!

Raspberry Pi header | cc-by-sa Elk tech@elk.audio

Elk Pi hat | Rev C
Sheet 14 / 15


TMS TDI TDO TCK 3V3

C PLD | c c-by-sa Elk tech@elk.au dio

Elk Pi ha t | Re v C
Sh e e t 1 5 / 1 5 | -11-6 16:26:24

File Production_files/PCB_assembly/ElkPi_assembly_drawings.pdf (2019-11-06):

AA

BB


View from Top side (Scale 2:1)

AA

BB


View from Bottom side (Scale 2:1)

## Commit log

2019-11-06 Added hardware files
    [AI.SchDoc, AO.SchDoc, Analog Inputs.SchDoc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]
2019-11-07 Added production files
    [ElkPi.DRL, ElkPi.GBL, ElkPi.GBO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]
2019-11-07 Removed duplicated assembly drawings
